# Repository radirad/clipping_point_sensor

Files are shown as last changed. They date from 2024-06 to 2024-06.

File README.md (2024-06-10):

# Clipping point sensor with vl53l1x sensor

In the world of RC drift competitions it is good to know how close is the car to the wall.
Here comes the proximiti meter witch shows this on LED display.

This project is based on Arduino nano board that gets distance from laser sensor vl53l1x an displays it on ws2812b RGB LED dtripe.
Similar sensors were used in RC drift competitions in poland D10 Battle of poland and germany Clash of Titans.

A lot of people asked me how to get such clpping point. Questions from RC drift community that supported me in my projects. 
So I've started new project that comes with guidelines as follows:
* Simple code,
* Use common modules of electronic components,
* Three elements board that is easy to assemble,
* Complete 3D project.

And it's done. 

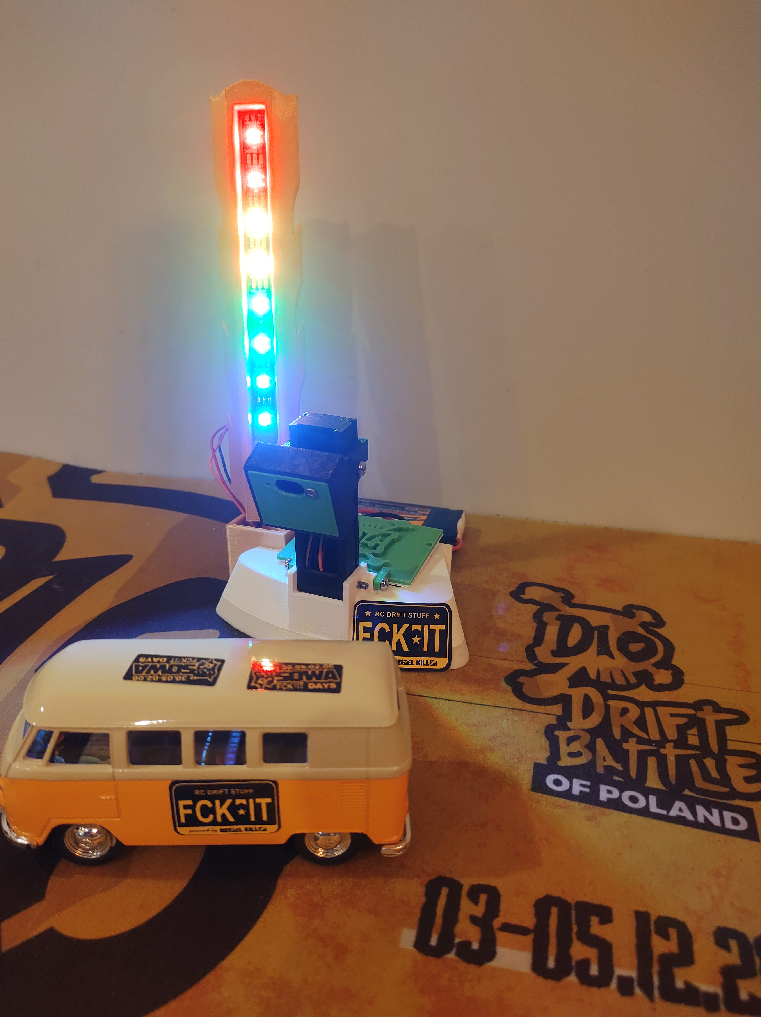
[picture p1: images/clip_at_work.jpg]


# Things to buy:
* Step-down converter 12-24V input, 5V 3A output
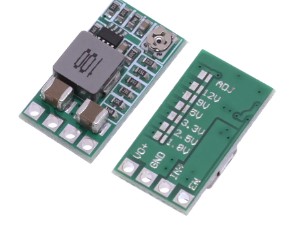
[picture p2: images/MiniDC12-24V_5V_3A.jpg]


* Arduino Nano
* Laser sensor VL53L1X (ToF)
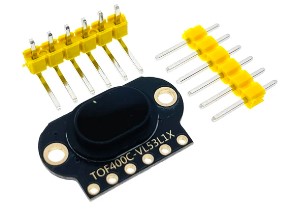
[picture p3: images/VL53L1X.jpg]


* DC5V WS2812B Led Strip 60leds/m 
* Resistor 470 Ohm
* JST 2Pin connector
* JST 3Pin connector
* JST 5Pin connector
* BLS 6Pin connector
* Universal board
* Wires
* Screws

# Circuit diagram

Simple circuit diagram.
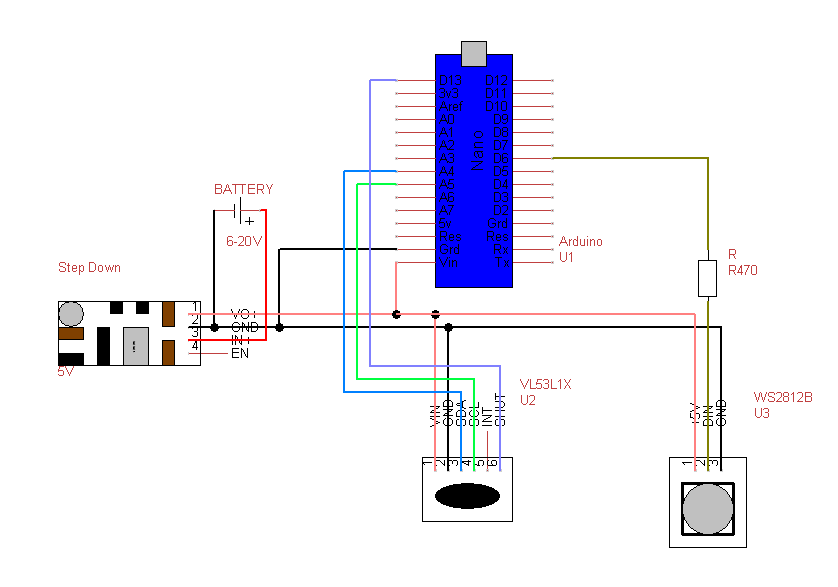
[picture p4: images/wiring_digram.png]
Circuit diagram


Universal small PCB board is enough to assemble.
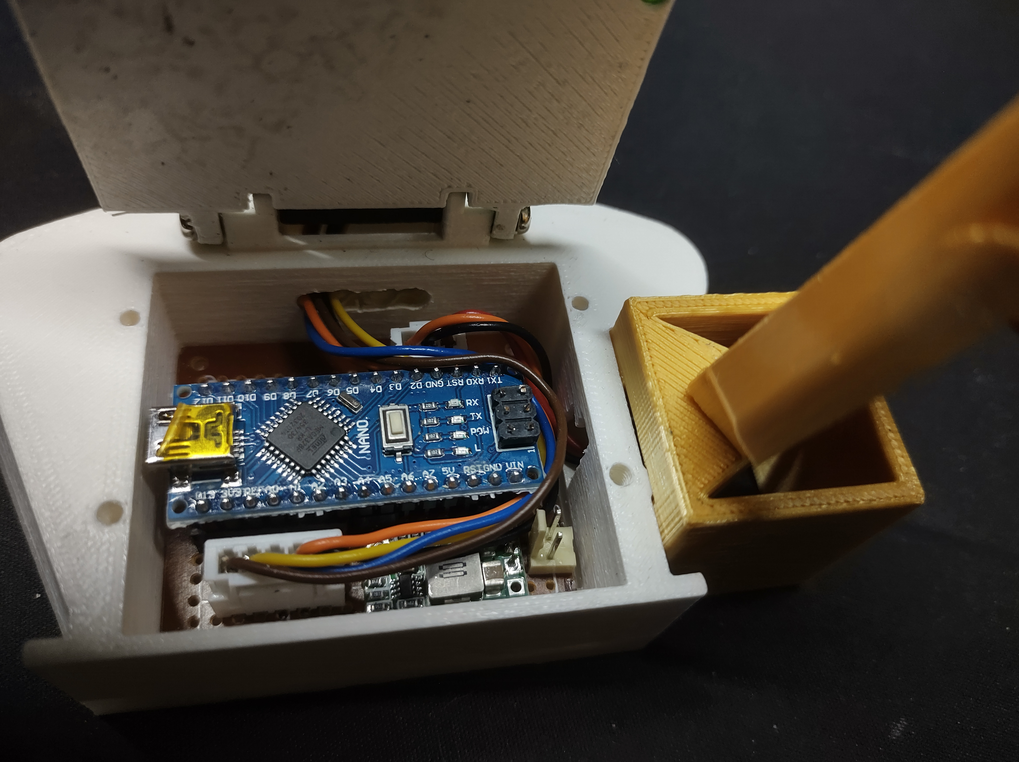
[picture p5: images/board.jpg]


# The code
After assembling all together using Arduino IDE code can be uploaded to device.

Full code you can find in arduino folder.

You need to install addition library Adafruit_NeoPixel for manaing LEDs, and VL53L1X from Pololu to operate laser sensor.

## How it works

At first range when program will operate is set.
```
int min_range=90;
int max_range=260;
int mid_range=(max_range-min_range)/4;
```
LED's are in four groups so mid_range is needed for flash next group.

When sensor detects object in max_range it sets colors of pixels in distance groups 1 to 4.

If object is out of range program is counting to value set in count variable end then clear LEDs.

It is possible to see the output of sensor in Arduino IDE monitor when debug flag is set.

For some disturbence in sensor there is check for not getting siglal from it and reset if it's still.

# The body
Full 3D body project is available in 3d_prints folder

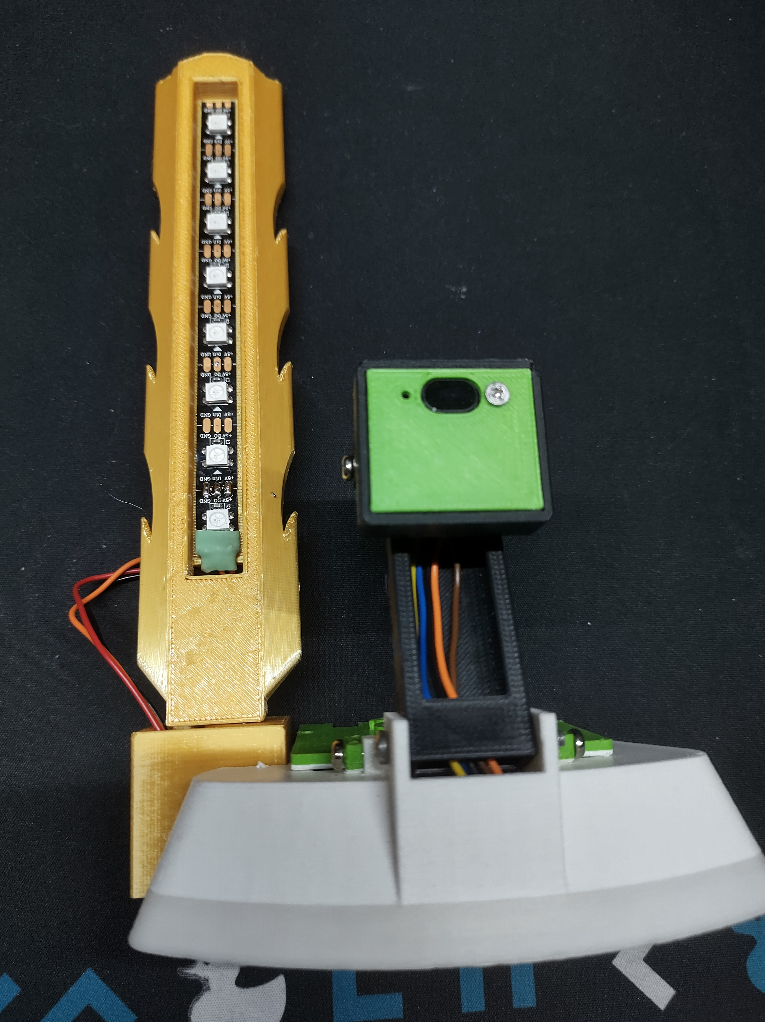
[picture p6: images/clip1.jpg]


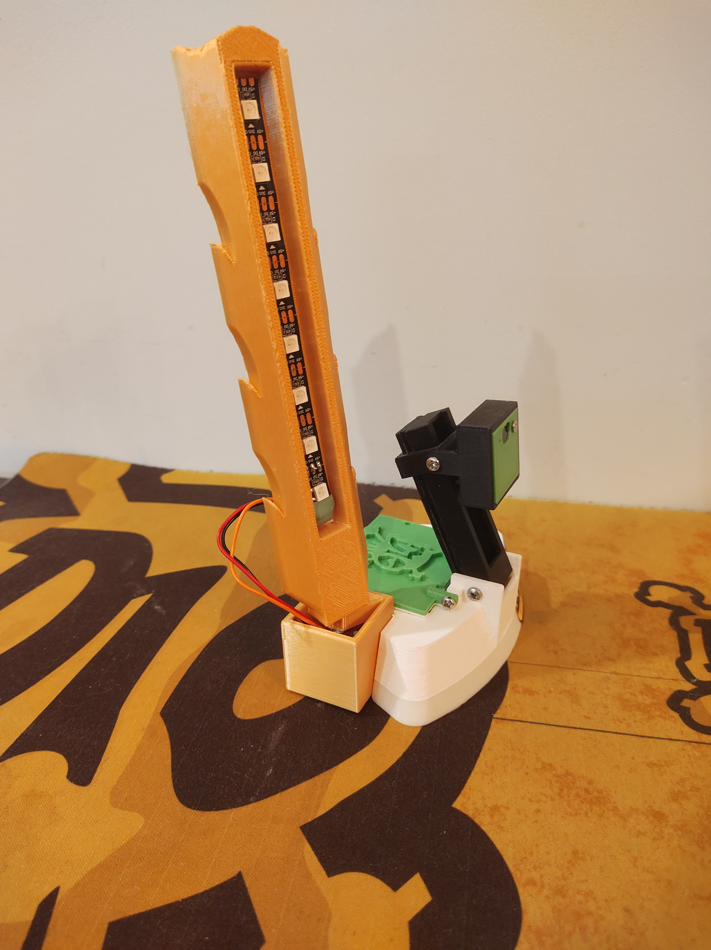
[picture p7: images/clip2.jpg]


For LED cover you can use 12mm cover from led profile for now

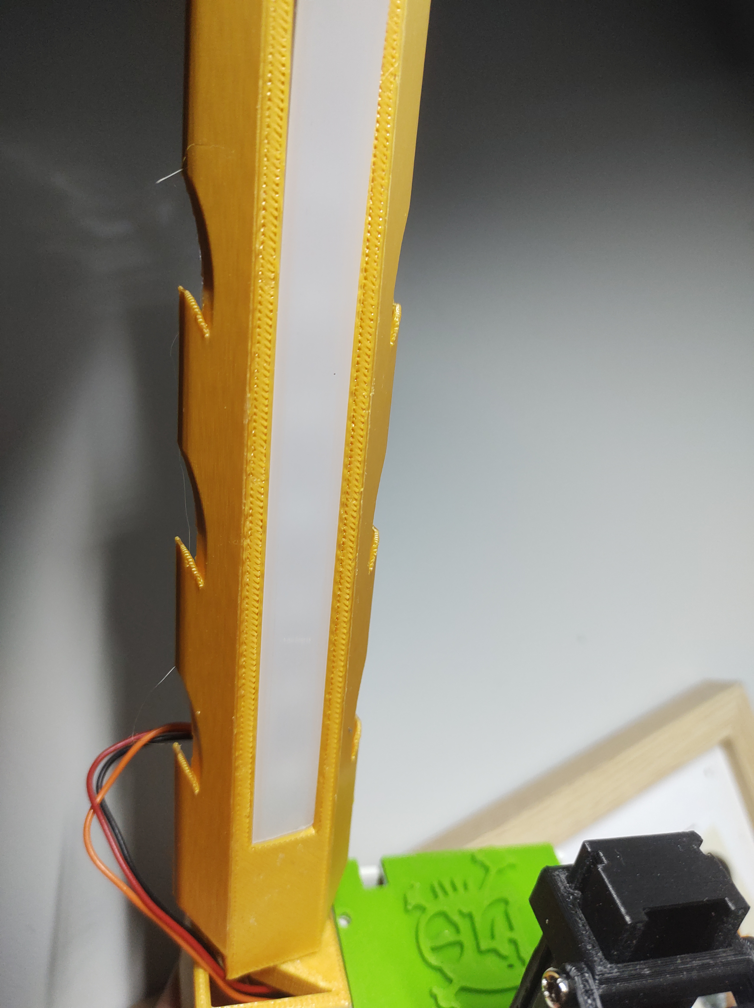
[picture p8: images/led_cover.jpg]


# The End
I must thank Marcin Wojcik ( https://fckit.pl ) and Rock Stopar for pushing me to finish this project.

If you find this project usefull, you can support me in continuing my work here
 https://www.paypal.com/donate/?business=YUMQAZ7P7YHWA&no_recurring=1&currency_code=EUR

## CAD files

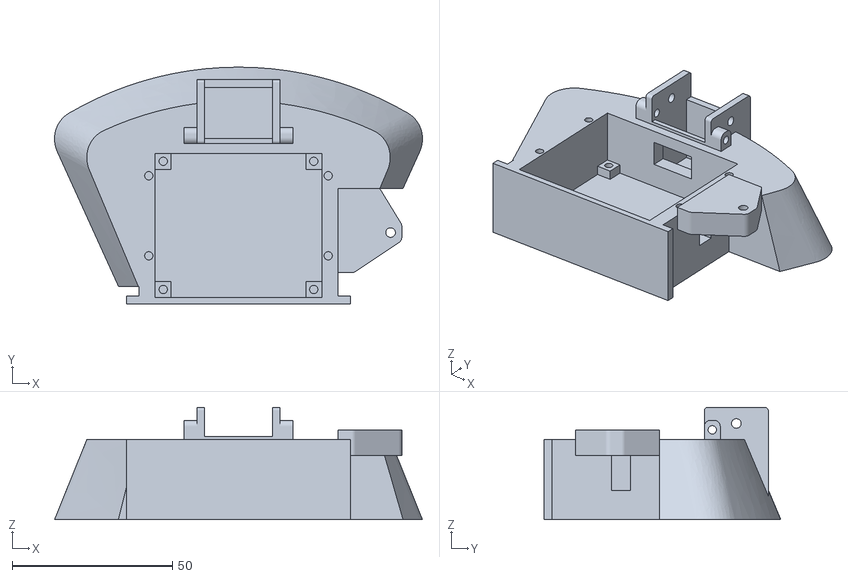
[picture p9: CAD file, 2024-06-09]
3d_prints/clip-main.stl
114.9 x 73.9 x 35.0

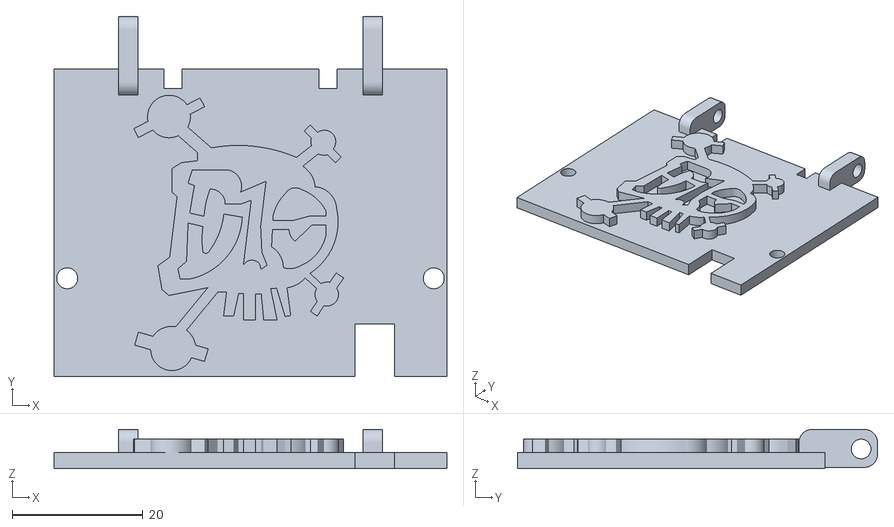
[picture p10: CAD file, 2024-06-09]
3d_prints/clip-cover.stl
60.0 x 55.0 x 6.00

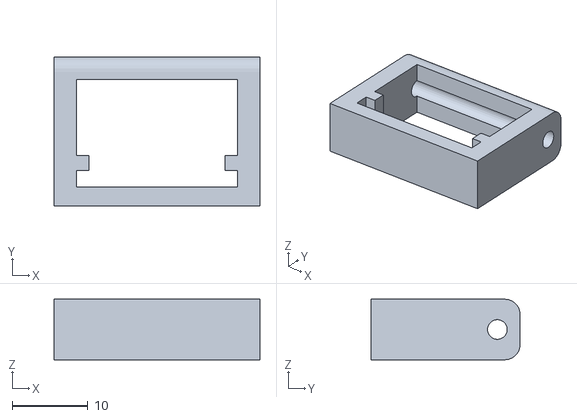
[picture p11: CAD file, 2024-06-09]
3d_prints/sensor-mount.stl
27.2 x 19.7 x 8.00

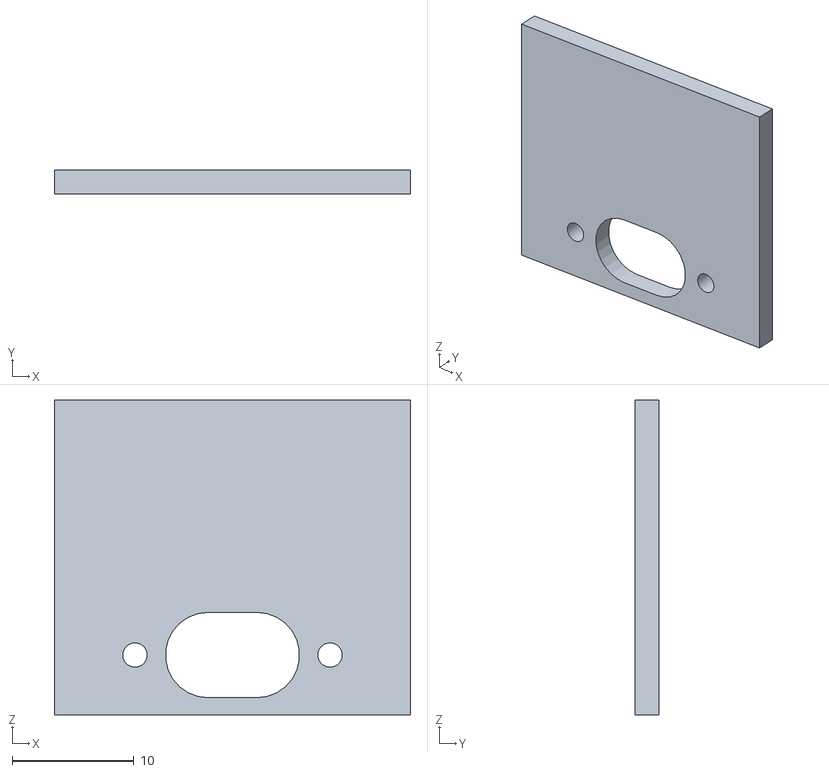
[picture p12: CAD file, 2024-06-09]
3d_prints/sensor-front.stl
29.2 x 2.00 x 25.8

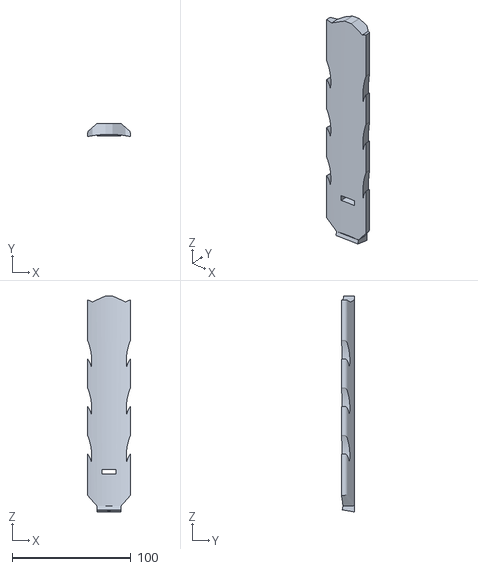
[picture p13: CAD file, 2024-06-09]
3d_prints/clip-led-display.stl
36.0 x 11.2 x 181.9

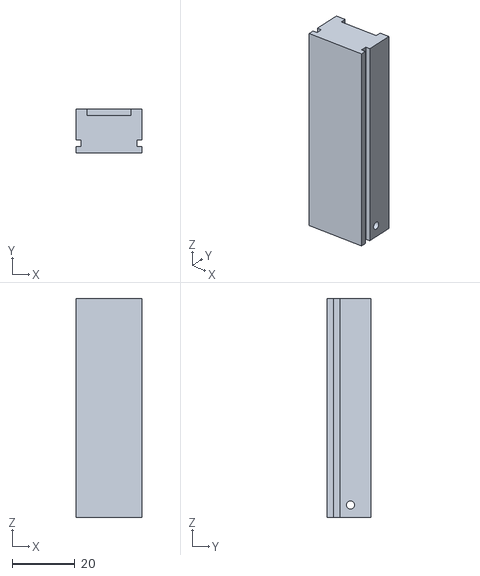
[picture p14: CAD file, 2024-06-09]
3d_prints/sensor-slope.stl
21.0 x 14.0 x 70.0

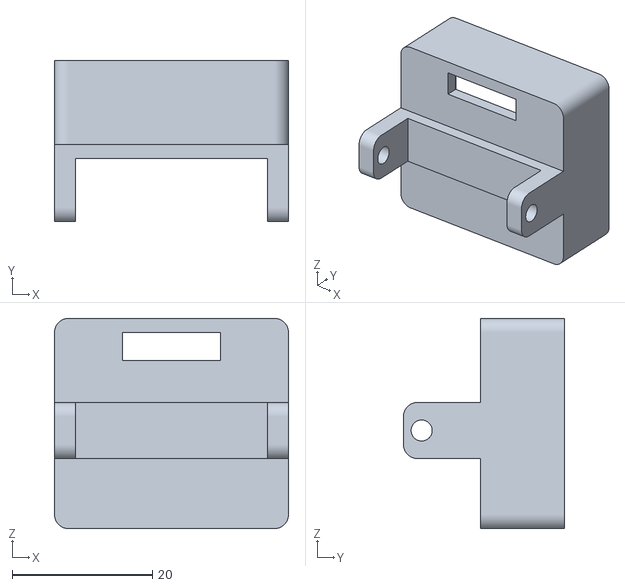
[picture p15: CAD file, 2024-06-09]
3d_prints/sensor-body.stl
33.4 x 23.0 x 30.0

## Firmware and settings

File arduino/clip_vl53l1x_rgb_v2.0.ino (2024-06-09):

#include <Wire.h>
#include <VL53L1X.h>
#include <Adafruit_NeoPixel.h>
#include "classes.h"

using namespace std;
#define XSHUT_pin1 13

#define LED_PIN 2
#define LEDS 8
Adafruit_NeoPixel pixels = Adafruit_NeoPixel(LEDS, LED_PIN, NEO_GRB + NEO_KHZ800);

ColourRGB CR[4]={ ColourRGB("Red",255,0,0),
                  ColourRGB("Yellow",253,166,0),
                  ColourRGB("Green",0,255,0),
                  ColourRGB("Blue",0,0,255)
                };

//Actual colour
int actColour=0;

// Counters //
int count=20,count_tmp=0,DIST;
unsigned long tmp_DIST,tmp_DIST_MAX=3000;

// Enable debugging mode //
int debug=1;

// Set range where sensor will operate //
int min_range=90;
int max_range=260;
int mid_range=(max_range-min_range)/4;

// Reset counters
int xreset=0; 
int xnotreset=0;

// Initialise sensor //
VL53L1X sensor;

void reset() { 
  sensor.stopContinuous();
  delay(10);
  asm volatile ("jmp 0"); 
}

void setup(){
  pixels.begin();
 
  while (!Serial) {}
  if(debug){ Serial.begin(115200); }
  pinMode(XSHUT_pin1, OUTPUT);
  Wire.begin();
  Wire.setClock(400000); // use 400 kHz I2C

  pinMode(XSHUT_pin1, INPUT);

  sensor.setTimeout(300);
  if (!sensor.init()){
    if(debug){ Serial.println("Failed to detect and initialize sensor!");}
    while (1);
  }

  // Use long distance mode and allow up to 50000 us (50 ms) for a measurement.
  // You can change these settings to adjust the performance of the sensor, but
  // the minimum timing budget is 20 ms for short distance mode and 33 ms for
  // medium and long distance modes. See the VL53L1X datasheet for more
  // information on range and timing limits.
  sensor.setDistanceMode(VL53L1X::Long);
  sensor.setMeasurementTimingBudget(30000);

  // Start continuous readings at a rate of one measurement every 50 ms (the
  // inter-measurement period). This period should be at least as long as the
  // timing budget.
  sensor.startContinuous(12);

}

void loop(){
	
	tmp_DIST = sensor.read();

// Ccheck for sensor not operating
if(tmp_DIST==-1){
  xreset++;
  xnotreset=1;
  if(xreset>20)reset();
}else if(xnotreset!=0){
  xnotreset++;
  if(xnotreset>100){
    xnotreset=0;
    xreset=0;
  }
}

// Check for no object in range //
	if(tmp_DIST>max_range){
		count_tmp++;
	}

	if(tmp_DIST<tmp_DIST_MAX){
		tmp_DIST_MAX=tmp_DIST;
		if ( tmp_DIST < min_range ) { DIST=1;}
		else if ( tmp_DIST < (min_range+mid_range)) { DIST=2;}
		else if ( tmp_DIST < (max_range-mid_range) ) { DIST=3;} 
		else if ( tmp_DIST < max_range ) { DIST=4;}
		else { DIST=0;}
			
		if(DIST<=4 && DIST>0){
      actColour=3;
      pixels.setPixelColor(0, CR[actColour].getRed(), CR[actColour].getGreen(), CR[actColour].getBlue());
      pixels.setPixelColor(1, CR[actColour].getRed(), CR[actColour].getGreen(), CR[actColour].getBlue());
      pixels.show();
		}
		if(DIST<=3 && DIST>0){
      actColour=2;
      pixels.setPixelColor(2, CR[actColour].getRed(), CR[actColour].getGreen(), CR[actColour].getBlue());
      pixels.setPixelColor(3, CR[actColour].getRed(), CR[actColour].getGreen(), CR[actColour].getBlue());
      pixels.show();
		}
		if(DIST<=2 && DIST>0){
      actColour=1;
      pixels.setPixelColor(4, CR[actColour].getRed(), CR[actColour].getGreen(), CR[actColour].getBlue());
      pixels.setPixelColor(5, CR[actColour].getRed(), CR[actColour].getGreen(), CR[actColour].getBlue());
      pixels.show();
  	}
		if(DIST==1){
      actColour=0;
      pixels.setPixelColor(6, CR[actColour].getRed(), CR[actColour].getGreen(), CR[actColour].getBlue());
      pixels.setPixelColor(7, CR[actColour].getRed(), CR[actColour].getGreen(), CR[actColour].getBlue());
      pixels.show();
		}				
	}

  if(debug){
    Serial.print(tmp_DIST);
    Serial.print(" - ");
    Serial.print(DIST);
    Serial.print(" - ");
    Serial.print(tmp_DIST_MAX);
    if (sensor.timeoutOccurred()) { Serial.print(" TIMEOUT"); }
    Serial.println();
  }

// No object in range, clear LEDs and counters //
	if(count_tmp>count){
		if(DIST>0){
			_delay_ms(500);
		}else{
			_delay_ms(50);
		}
		count_tmp=0;
		tmp_DIST_MAX=3000;
		DIST=0;
    pixels.clear();
    pixels.show();
	}	

}
